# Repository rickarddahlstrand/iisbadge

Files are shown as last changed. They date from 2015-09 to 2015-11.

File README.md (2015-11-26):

# iisbadge
The IIS Internetdagarna Badge project.

Here is a collection of the Eagle source files for the IIS Internetdagarna badge projekt.

All the parts can be ordered from Seeedstudio and their excellent OPL:
http://www.seeedstudio.com/depot/OPLopen-parts-library-catalog-c-136_138/?ref=crumb

* 1 x DIP Toggle Switch;6P-2.54-L9.0*W3.5*H3.2mm(311030004)
* 2 x DIP LED Vaporous-Red-Red(304090059)
* 1 x Lithium-ion Battery 3V-40mAh(313010013)
* 1 x DIP Battery Cell Holder;(320170002)
* 1 x Folding Clasps(323050000

Needed for the geekprt:
* 1 x DIP Black Male Header VERT;(320020010)
* 2 x DIP RES 100R-5%-1/4W(301020017)


<br>
<a href="https://github.com/rickarddahlstrand/iisbadge/raw/master/intdagarnapulseheart.ino">Code example for this here!</a>

License: CC BY-NC-SA 3.0

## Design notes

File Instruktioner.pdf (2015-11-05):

### LÖD DITT EGET LYSANDE INTERNETDAGARNAHJÄRTA!

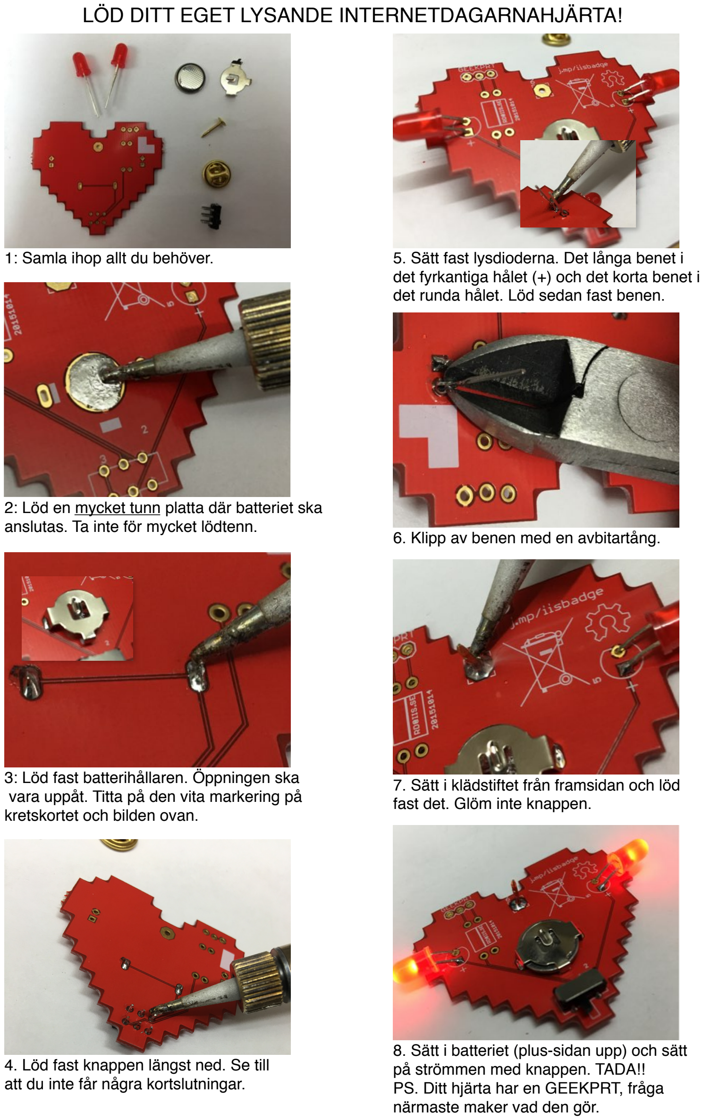
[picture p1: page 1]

1: Samla ihop allt du behöver.

2: Löd en mycket tunn platta där batteriet ska anslutas. Ta inte för mycket lödtenn.

3: Löd fast batterihållaren. Öppningen ska vara uppåt. Titta på den vita markering på kretskortet och bilden ovan.

4. Löd fast knappen längst ned. Se till att du inte får några kortslutningar.
5. Sätt fast lysdioderna. Det långa benet i det fyrkantiga hålet (+) och det korta benet i det runda hålet. Löd sedan fast benen.
6. Klipp av benen med en avbitartång.
7. Sätt i klädstiftet från framsidan och löd fast det. Glöm inte knappen.
8. Sätt i batteriet (plus-sidan upp) och sätt på strömmen med knappen. TADA!!
PS. Ditt hjärta har en GEEKPRT, fråga närmaste maker vad den gör.

### LÖD DITT EGET LYSANDE INTERNETDAGARNAHJÄRTA!

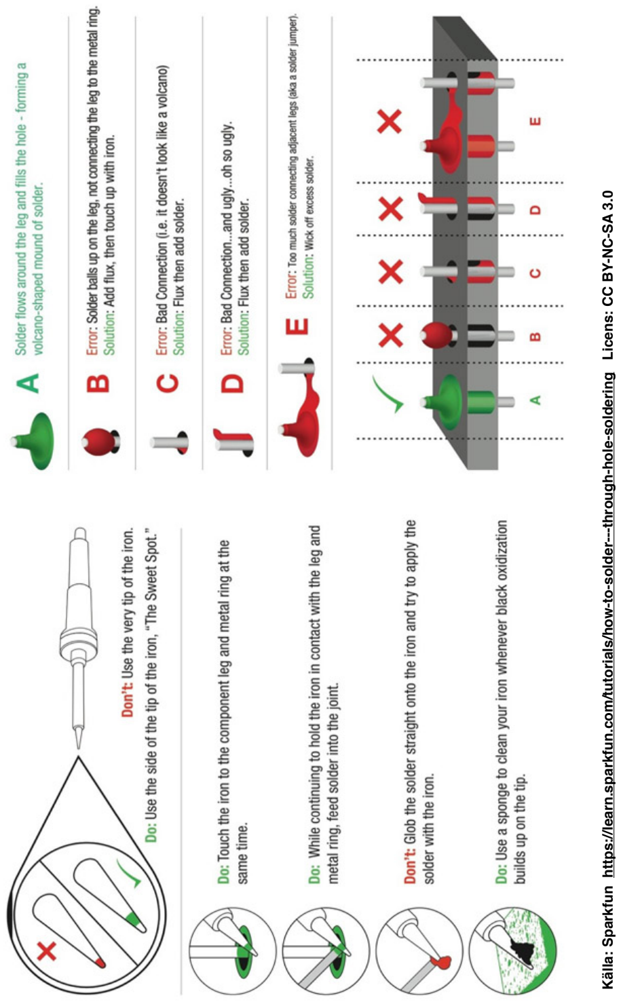
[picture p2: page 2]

Källa: Sparkfun https://learn.sparkfun.com/tutorials/how-to-solder---through-hole-soldering Licens: CC BY-NC-SA 3.0

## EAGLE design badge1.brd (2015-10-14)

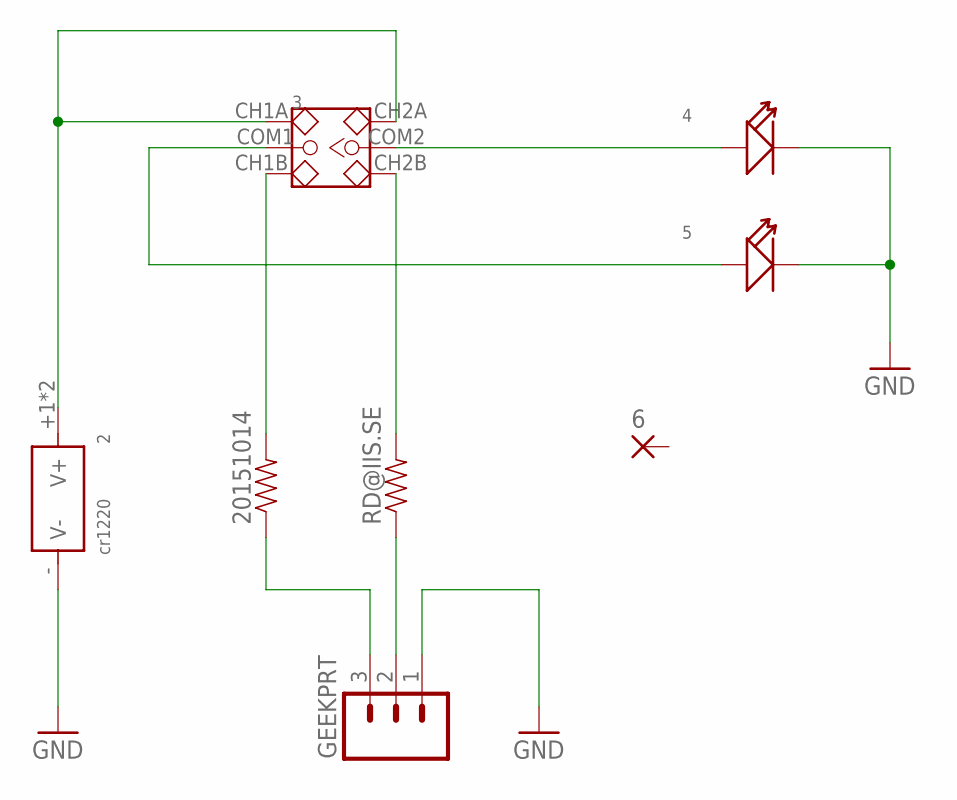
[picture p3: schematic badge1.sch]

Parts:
2: cr1220; BAT2P-13.5-CR1220
3: DIP-TOGGLE-SWITCH-2CH-(2X3P-2.54-90D)'90D'; SW6-2.54-9.0X3.5X3.2MM-90D
4, 5: LED'5MM'; LED2-2.54-D5.0MM
6: 3,81/1,4
20151014: RESISTORPTH-1/4W; AXIAL-0.4
GEEKPRT: M03LOCK; 1X03_LOCK
RD@IIS.SE: RESISTORPTH-1/4W; AXIAL-0.4

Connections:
GND: 2.- (V-), 4.-, 5.-, GEEKPRT.1
unnamed: 3.COM2, 4.+
unnamed: 3.COM1, 5.+
unnamed: 2.+1 (V+), 2.+2 (V+), 3.CH1A, 3.CH2A
unnamed: GEEKPRT.2, RD@IIS.SE.P$1 (1)
unnamed: 3.CH1B, 20151014.P$2 (2)
unnamed: 3.CH2B, RD@IIS.SE.P$2 (2)
unnamed: 20151014.P$1 (1), GEEKPRT.3

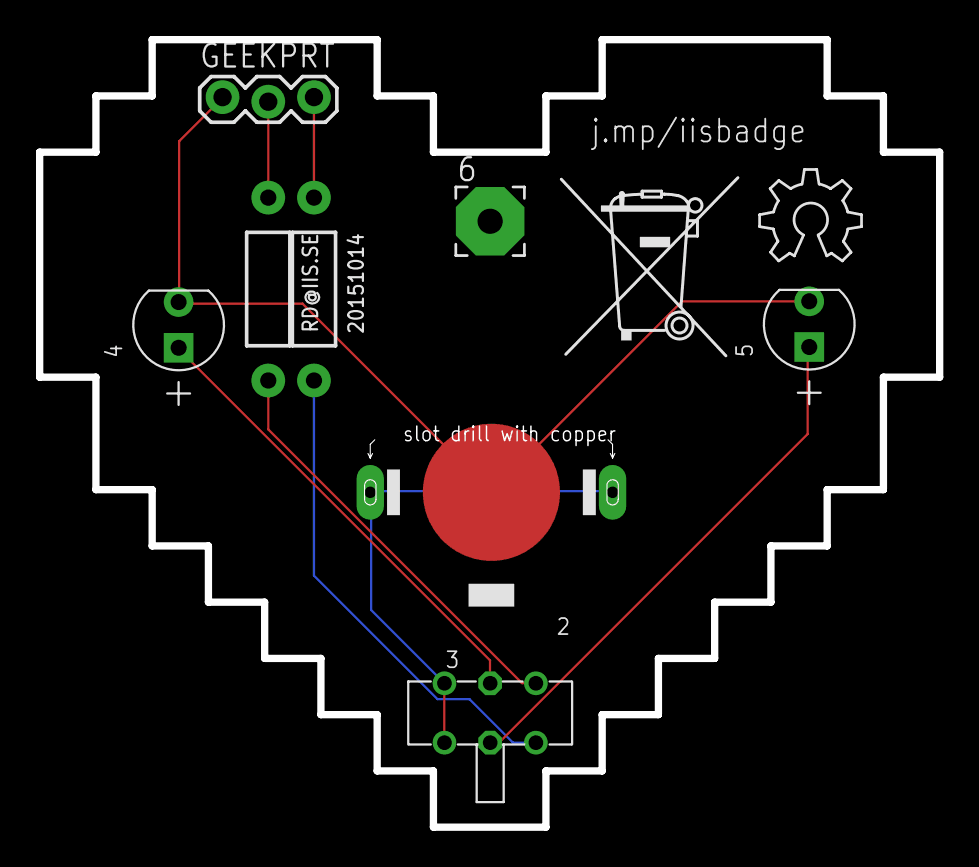
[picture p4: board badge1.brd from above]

Board: 2 copper layers, 50.0 x 43.8 mm, 10 parts (0 on the bottom side), 8 nets.

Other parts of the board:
U$1: OSHW_6X200_NOTEXT
U$3: MUELLTONNE_10.00

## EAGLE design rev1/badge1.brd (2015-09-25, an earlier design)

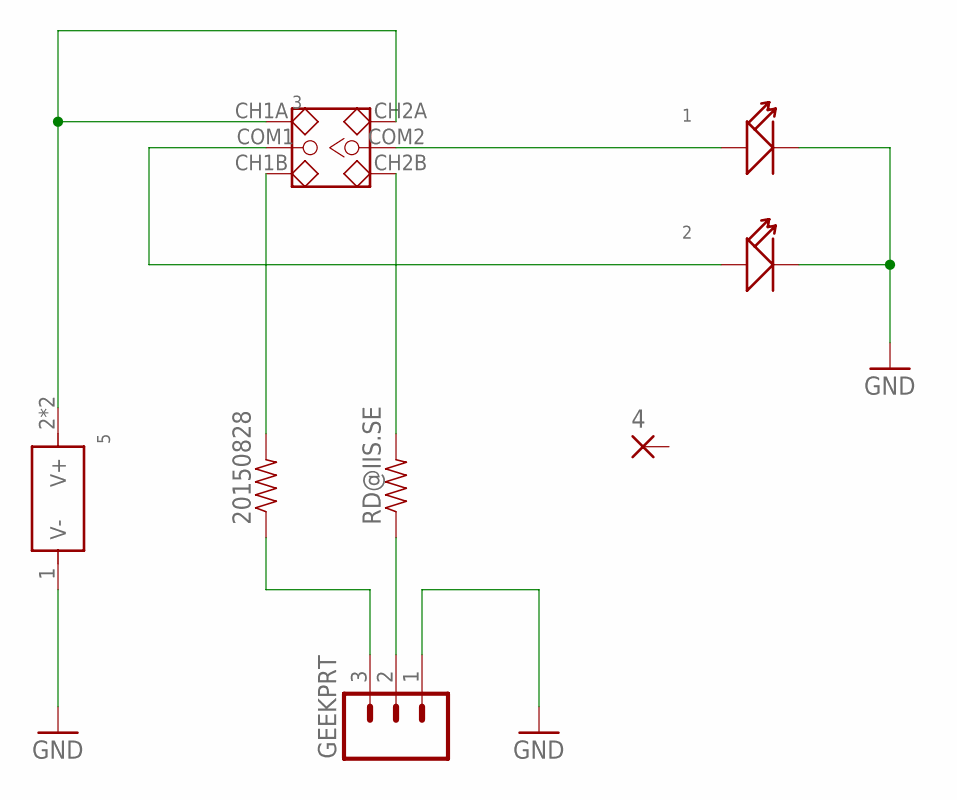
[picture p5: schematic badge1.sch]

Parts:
1, 2: LED'5MM'; LED2-2.54-D5.0MM
3: DIP-TOGGLE-SWITCH-2CH-(2X3P-2.54-90D)'90D'; SW6-2.54-9.0X3.5X3.2MM-90D
4: 3,81/1,4
5: BAT-HOLDER-2032; BAT2P-20.32-CR2032
20150828: RESISTORPTH-1/4W; AXIAL-0.4
GEEKPRT: M03LOCK; 1X03_LOCK
RD@IIS.SE: RESISTORPTH-1/4W; AXIAL-0.4

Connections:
GND: 1.-, 2.-, 5.1 (V-), GEEKPRT.1
unnamed: 1.+, 3.COM2
unnamed: 2.+, 3.COM1
unnamed: 3.CH1A, 3.CH2A, 5.2 (V+), 5.3 (V+)
unnamed: GEEKPRT.2, RD@IIS.SE.P$1 (1)
unnamed: 3.CH1B, 20150828.P$2 (2)
unnamed: 3.CH2B, RD@IIS.SE.P$2 (2)
unnamed: 20150828.P$1 (1), GEEKPRT.3

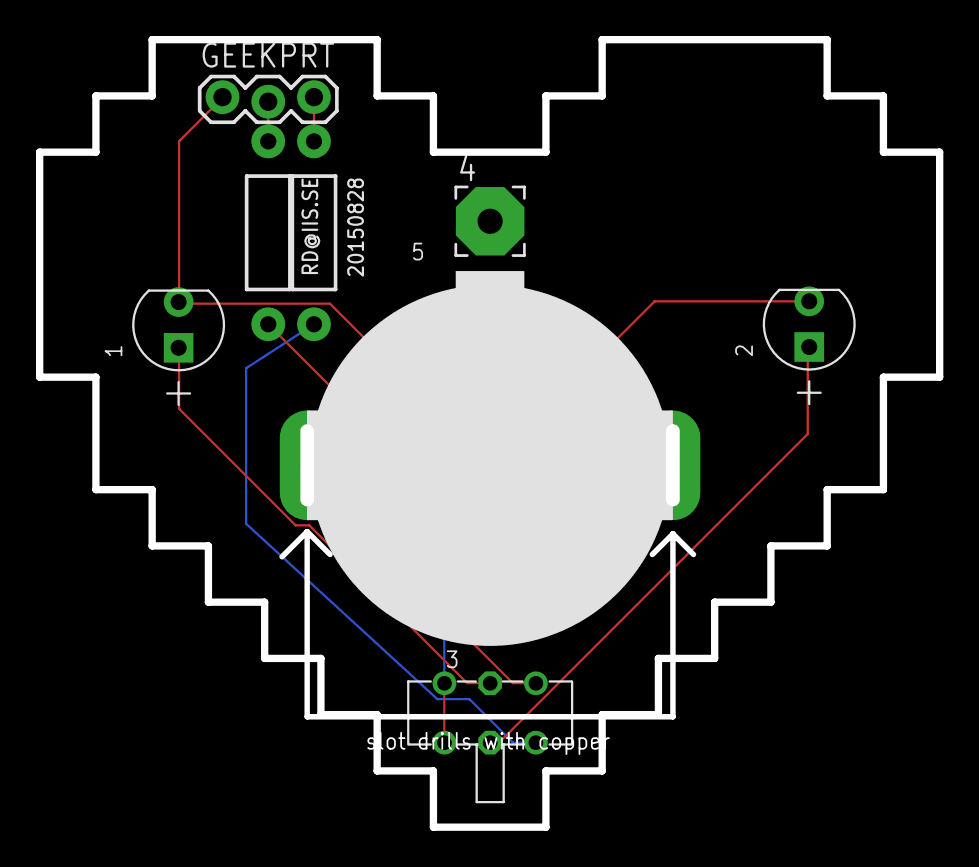
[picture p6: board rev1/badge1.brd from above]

Board: 2 copper layers, 50.0 x 43.8 mm, 8 parts (0 on the bottom side), 8 nets.

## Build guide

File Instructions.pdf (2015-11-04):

### SOLDER YOUR OWN GLOWING INTERNETDAGARNA BADGE

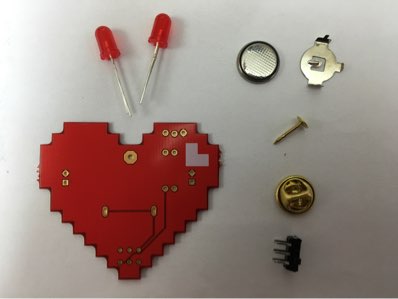
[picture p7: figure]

1: Collect what you need to build the badge.

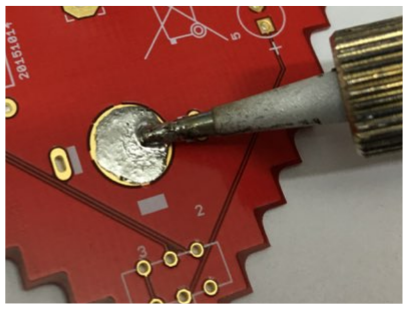
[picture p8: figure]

2: Heat and tin the battery connector with some solder. Not too thick!

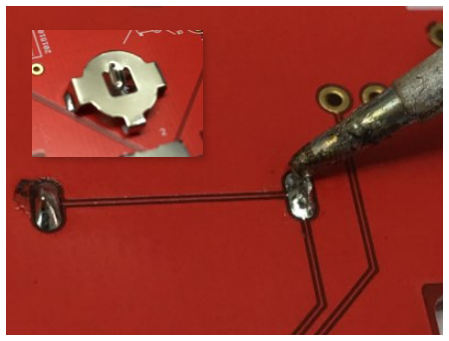
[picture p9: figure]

3: Solder the battery holder. Battery should go in at the top (see picture below for correct orientation).

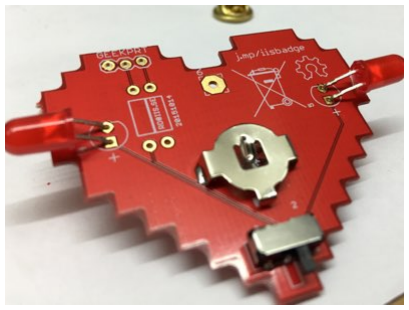
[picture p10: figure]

4. Place LEDs. Long leg in the square hole, short leg in the round hole. Bend legs before soldering to make the LEDs stand out.

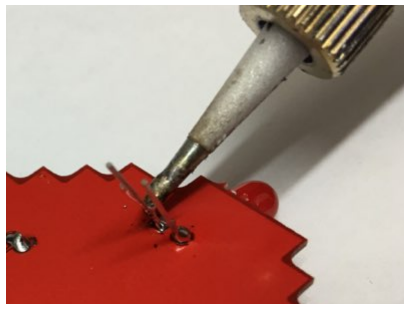
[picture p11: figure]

5. Solder all four legs of the LEDs.

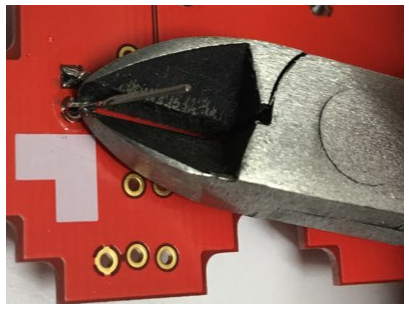
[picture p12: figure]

6. Cut the legs of the LEDs using a wirecutter. Don’t cut to close to the badge!

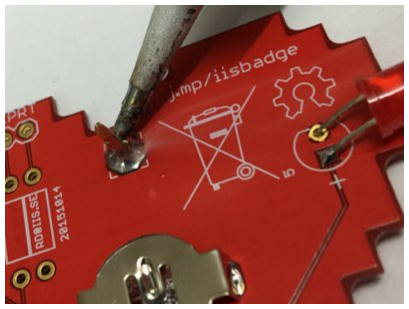
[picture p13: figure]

7. Insert the pin from the front and solder it. This is what you stick into your shirt.
Don’t forget the clasp!

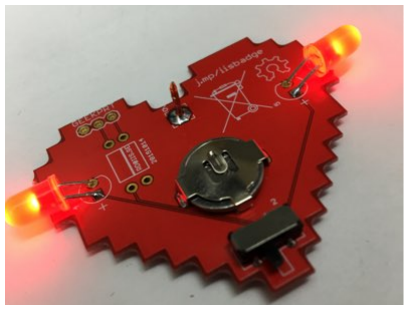
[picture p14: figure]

8. Connect battery (plus-side up) and turn on the switch! TADA!! Use the GEEKPRT for more Arduino-fun, parts on request.

### SOLDER YOUR OWN GLOWING INTERNETDAGARNA BADGE

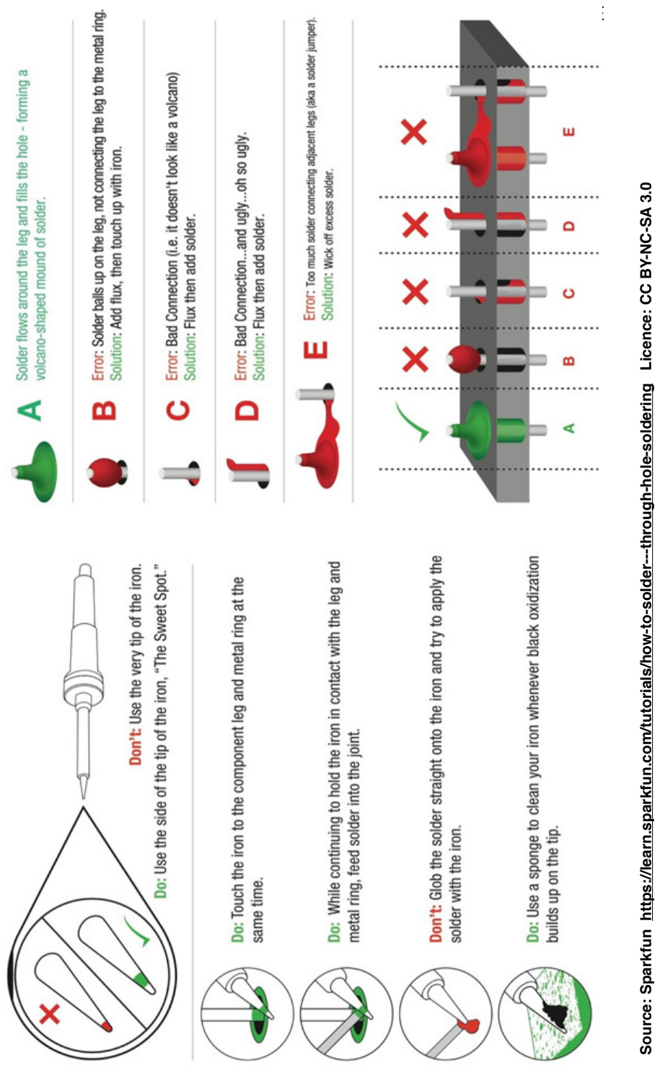
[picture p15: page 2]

Source: Sparkfun https://learn.sparkfun.com/tutorials/how-to-solder---through-hole-soldering Licence: CC BY-NC-SA 3.0

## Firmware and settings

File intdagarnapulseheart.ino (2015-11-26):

#define ledPin1    10   
#define ledPin2    11   

void setup()
{
  pinMode(ledPin1, OUTPUT);
  pinMode(ledPin2, OUTPUT);
  pinMode(12, OUTPUT);
  digitalWrite(12, LOW);
}

void loop()
{
  for(int fadeValue = 0 ; fadeValue <= 255; fadeValue +=5) { 
    analogWrite(ledPin1, fadeValue);         
    analogWrite(ledPin2, 255-fadeValue);         
    delay(15);                            
  } 
  
  for(int fadeValue = 200 ; fadeValue >= 0; fadeValue -=5) { 
    analogWrite(ledPin1, fadeValue);         
    analogWrite(ledPin2, 255-fadeValue);         
    delay(25);                            
  } 
}

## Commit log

2015-09-25 First commit
    ..
    [badge1.GBL, badge1.GBO, badge1.GBP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]
2015-09-25 Second rev send to dirtypcb
    [badge1.GBL, badge1.GBO, badge1.GBP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]
2015-10-14 Rev 3 sent to Cogra
    [badge1.GBL, badge1.GBO, badge1.GBP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]

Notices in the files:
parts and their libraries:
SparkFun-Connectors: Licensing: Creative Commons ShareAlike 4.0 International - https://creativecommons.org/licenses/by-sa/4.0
